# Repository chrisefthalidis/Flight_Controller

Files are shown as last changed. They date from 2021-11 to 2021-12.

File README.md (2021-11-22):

This board is an embedded system based on the STM32F405RGT6 microcontroller. It incorporates an MPU9250 Inertial
Measurement Unit for attitude estimation, an SPL06-007 barometer for altitude estimation and a TESEO-LIV3F GNSS
receiver for position estimation. There is also a second Radio Transceiver board (based on the nRF24L01+ transceiver)
that is connected as a shield to the Flight Controller board. You will find all the necessary PCB design files from
Altium and KiCad inside the respective folders. The firmware is not fully finished yet, but you will find most of the
existing files inside the 'Firmware' folder, including ST's HAL drivers generated by STM32CubeMX, an SPL06-007
driver, an nRF24L01+ driver, a Complementary Filter implementation in C, a Kalman Filter implementation in C++, as well
as a PID Controller implementation in both C and C++. The MPU9250 driver, as well as the main.c function are coming
soon. The basic idea is that we read the values from all our sensors, we deploy some state estimation and sensor
fusion algorithms, and we use these states to control a quadcopter UAV. There is also an additional 'Radio Controller
(Ground Module)' board, that you will find on my GitHub page, which we can use to remotely control the quadcopter's
altitude using the on-board potentiometer.

P.S. These boards are not perfect in any way. They have some design mistakes, since they were 2 of my first boards.
I've learnt a lot since, and i keep getting better with each board that i design. If you have any questions, please
contact me at chrisefthalidis@gmail.com

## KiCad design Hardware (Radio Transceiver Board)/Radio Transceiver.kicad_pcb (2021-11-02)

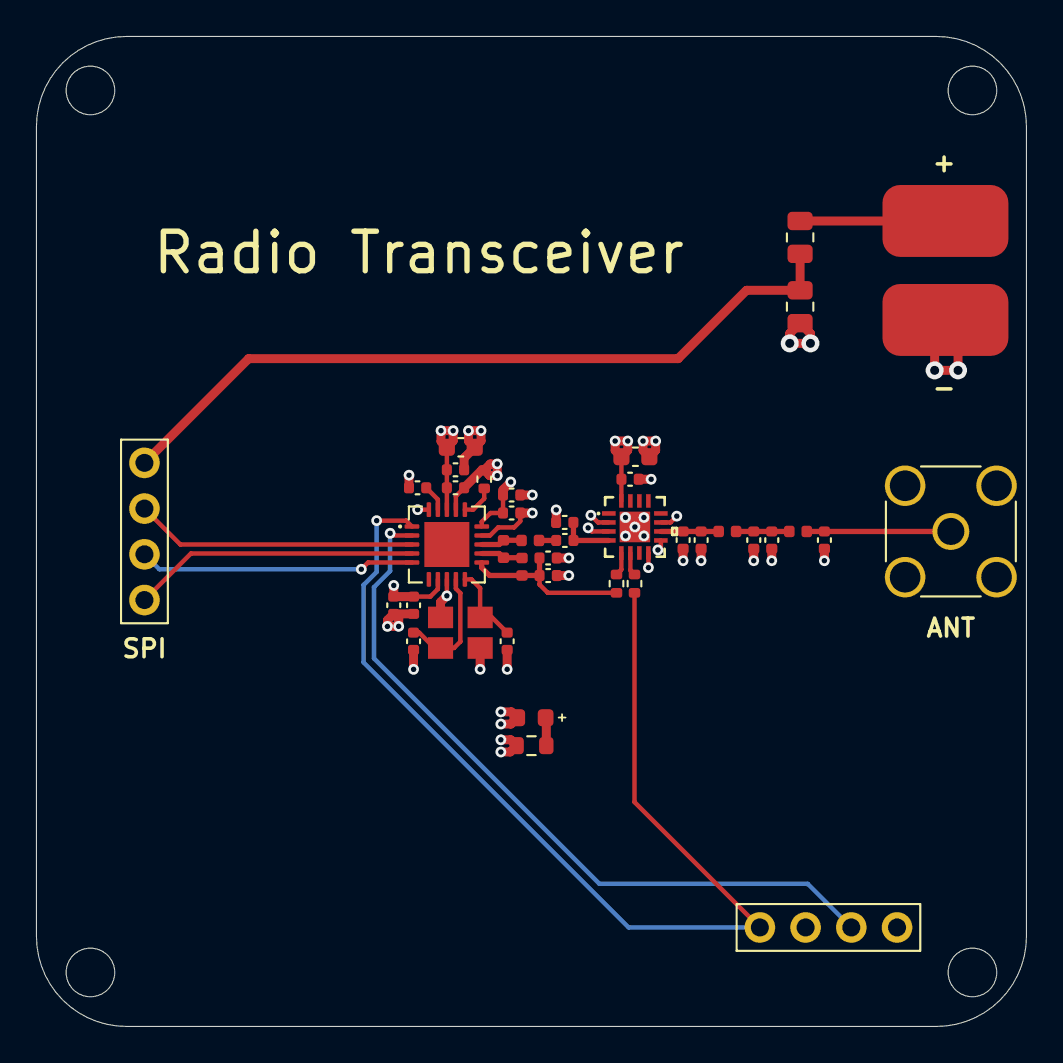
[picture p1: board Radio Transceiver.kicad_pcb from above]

Board: 4 copper layers, 55.0 x 55.0 mm, 44 parts (0 on the bottom side), 24 nets.

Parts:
C1: 1uF; C_0603_1608Metric
C2: 220pF; C_0402_1005Metric
C3: 4.7uF; C_0603_1608Metric
C4, C6, C8: 10nF; C_0402_1005Metric
C5, C7, C9: 1nF; C_0402_1005Metric
C10: 4.7pF; C_0402_1005Metric
C11: 2.2nF; C_0402_1005Metric
C12, C18, C19, C20, C21: 1.5pF; C_0402_1005Metric
C13: 1pF; C_0402_1005Metric
C14: 33nF; C_0402_1005Metric
C15, C16: 12pF; C_0402_1005Metric
C17: 0.3pF; C_0402_1005Metric
D1: Green LED; LED_0603_1608Metric
H1, H2, H3, H4: MountingHole; MountingHole_2.7mm_M2.5
J1: KH-SMA-KE8-G; SMA_Amphenol_132291_Vertical
J2, J3: Conn_01x04; PinSocket_1x04_P2.54mm_Vertical
J4: Screw_Terminal_01x02; TerminalBlock_bornier-2_P5.08mm
L1: 2.7nH; L_0402_1005Metric
L2: 8.2nH; L_0402_1005Metric
L3: 3.9nH; L_0402_1005Metric
L4, L5: 2.4nH; L_0402_1005Metric
R1, R2: 1KΩ; R_0402_1005Metric
R3: 22ΚΩ; R_0402_1005Metric
R4: 33Ω; R_0603_1608Metric
R5: 30ΚΩ; R_0805_2012Metric
R6: 7.5ΚΩ; R_0805_2012Metric
U1: RFX2401C
U2: nRF24L01P; QFN-20-1EP_4x4mm_P0.5mm_EP2.5x2.5mm
Y1: X322516MLB4SI; Crystal_SMD_3225-4Pin_3.2x2.5mm

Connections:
+3V3: C1.1, C2.1, C3.1, C4.1, C5.1, C6.1, C7.1, C8.1, C9.1, J2.1, R4.1, U1.16, U2.7, U2.15, U2.18
+BATT: J4.1, R5.2
/ADC_IN: J3.4, R5.1, R6.2
/ANT: C17.1, C18.1, L4.2, U1.10
/ANT1: L1.2, L2.1, U2.12
/ANT2: L2.2, L3.2, U2.13
/CE: J2.4, R2.1, U2.1
/CSN: J2.2, U2.2
/MISO: J3.2, U2.5
/MOSI: J3.1, U2.4
/SCK: J3.3, U2.3
/TXRX: C12.1, C13.1, U1.4
/VDD_PA: C10.1, C11.1, L1.1, R1.1, U2.11
/XC1: C15.1, U2.10, Y1.1
/XC2: C16.1, U2.9, Y1.3
GND: C1.2, C2.2, C3.2, C4.2, C5.2, C6.2, C7.2, C8.2, C9.2, C10.2, C11.2, C13.2, C14.2, C15.2, C16.2, C17.2, C18.2, C19.2, C20.2, C21.2, D1.1, J1.2, J2.3, J4.2, R3.1, R6.1, U1.2, U1.3, U1.8, U1.9, U1.11, U1.17, U2.8, U2.14, U2.17, U2.20, Y1.2, Y1.4
unnamed: C12.2, L3.1
unnamed: C14.1, U2.19
unnamed: C19.1, C20.1, L4.1, L5.2
unnamed: C21.1, J1.1, L5.1
unnamed: D1.2, R4.2
unnamed: R1.2, U1.5
unnamed: R2.2, U1.6
unnamed: R3.2, U2.16

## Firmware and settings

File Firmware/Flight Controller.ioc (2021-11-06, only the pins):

Mcu.UserName=STM32F405RGTx
PA10.Signal=GPIO_Output
PA11.Signal=USB_OTG_FS_DM
PA12.Signal=USB_OTG_FS_DP
PA13.Signal=GPIO_Output
PA14.Signal=GPIO_Output
PA15.Signal=S_TIM2_CH1_ETR
PA2.Signal=S_TIM2_CH3
PA4.Signal=ADCx_IN4
PA5.Signal=SPI1_SCK
PA6.Signal=SPI1_MISO
PA7.Signal=SPI1_MOSI
PA8.Signal=I2C3_SCL
PA9.Signal=GPIO_Output
PB10.Signal=I2C2_SCL
PB11.Signal=I2C2_SDA
PB14.Signal=S_TIM12_CH1
PB6.Signal=I2C1_SCL
PB7.Signal=I2C1_SDA
PB9.Signal=S_TIM4_CH4
PC11.Signal=GPIO_Output
PC12.Signal=GPIO_Input
PC2.Signal=GPIO_Output
PC3.Signal=GPIO_Input
PC4.Signal=GPIO_Output
PC5.Signal=GPIO_Input
PC7.Signal=GPIO_Output
PC8.Signal=GPIO_Input
PC9.Signal=I2C3_SDA
PH0-OSC_IN.Signal=RCC_OSC_IN
PH1-OSC_OUT.Signal=RCC_OSC_OUT

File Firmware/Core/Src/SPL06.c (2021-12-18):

#include "SPL06.h"

void SPL06_Read_Register(uint8_t dev_addr, uint8_t reg_addr, uint8_t *data)
{
  HAL_I2C_Mem_Read(&hi2c1, dev_addr, reg_addr, I2C_MEMADD_SIZE_8BIT, data, 1, HAL_MAX_DELAY);
}

void SPL06_Read_Registers(uint8_t dev_addr, uint8_t reg_addr, uint8_t *data, uint8_t length)
{
  HAL_I2C_Mem_Read(&hi2c1, dev_addr, reg_addr, I2C_MEMADD_SIZE_8BIT, data, length, HAL_MAX_DELAY);
}

void SPL06_Write_Register(uint8_t dev_addr, uint8_t reg_addr, uint8_t *data)
{
  HAL_I2C_Mem_Write(&hi2c1, dev_addr, reg_addr, I2C_MEMADD_SIZE_8BIT, data, 1, HAL_MAX_DELAY);
}

void SPL06_Write_Registers(uint8_t dev_addr, uint8_t reg_addr, uint8_t *data, uint8_t length)
{
  HAL_I2C_Mem_Write(&hi2c1, dev_addr, reg_addr, I2C_MEMADD_SIZE_8BIT, data, length, HAL_MAX_DELAY);
}

void SPL06_Initialise(SPL06 *dev)
{
  dev->c00 = 0;
  dev->c10 = 0;

  dev->c20 = 0;
  dev->c30 = 0;
  dev->c01 = 0;
  dev->c11 = 0;
  dev->c21 = 0;

  dev->bar_bias = 0.f;
  dev->bar_alt_m = 0.f;

  uint8_t tx_data, rx_data[15];

  tx_data = 0x61; // Pressure measurement rate: 64, Pressure oversampling rate: 2
  SPL06_Write_Register(SPL06_ADDR, SPL06_REG_PRS_CFG, &tx_data);

  tx_data = 0xA1; // Temperature measurement rate: 4, Temperature oversampling rate: 2
  SPL06_Write_Register(SPL06_ADDR, SPL06_REG_TMP_CFG, &tx_data);

  tx_data = 0b0111; // Continuous pressure and temperature measurement
  SPL06_Write_Register(SPL06_ADDR, SPL06_REG_MEAS_CFG, &tx_data);

  // Read the Calibration Coefficients register
  SPL06_Read_Registers(SPL06_ADDR, SPL06_REG_COEF, rx_data, sizeof(rx_data));

  // Calculate the Calibration Coefficients
  dev->c00 = ((uint32_t)rx_data[0] << 12) | ((uint16_t)rx_data[1] << 4) | ((uint16_t)rx_data[2] >> 4);
  dev->c10 = ((uint32_t)(rx_data[2] & 0x0F)) << 16 | ((uint16_t)rx_data[3] << 8) | rx_data[4];
  dev->c01 = ((uint16_t)rx_data[5] << 8) | rx_data[6];
  dev->c11 = ((uint16_t)rx_data[7] << 8) | rx_data[8];
  dev->c20 = ((uint16_t)rx_data[9] << 8) | rx_data[10];
  dev->c21 = ((uint16_t)rx_data[11] << 8) | rx_data[12];
  dev->c30 = ((uint16_t)rx_data[13] << 8) | rx_data[14];

  if (dev->c00 & (1 << 19))
    dev->c00 = dev->c00 | 0xFFF00000;

  if (dev->c10 & (1 << 19))
    dev->c10 = dev->c10 | 0xFFF00000;
}

void SPL06_Calibrate(SPL06 *dev)
{
  float avg_bar_bias = 0.f;

  // Take 2000 measurements and average them to get the bias
  for (uint16_t i = 0; i < 2010; i++)
  {
    SPL06_Read(dev);

    if (i >= 10)
      avg_bar_bias += dev->bar_alt_m;

    HAL_Delay(10);
  }

  dev->bar_bias = avg_bar_bias / 2000;
}

void SPL06_Read(SPL06 *dev)
{
  uint8_t data[6];
  int32_t press_raw = 0, temp_raw = 0;
  float press_raw_scaled = 0.f, temp_raw_scaled = 0.f, press_hPa = 0.f;

  // Read all the data registers
  SPL06_Read_Registers(SPL06_ADDR, SPL06_REG_PSR_B2, data, sizeof(data));

  // Calculate raw pressure and temperature values
  press_raw = ((uint32_t)data[0] << 16) | ((uint16_t)data[1] << 8) | data[2];
  temp_raw = ((uint32_t)data[3] << 16) | ((uint16_t)data[4] << 8) | data[5];

  if (press_raw & (1 << 23))
    press_raw = press_raw | 0xFF000000;

  if (temp_raw & (1 << 23))
    temp_raw = temp_raw | 0xFF000000;

  press_raw_scaled = (float)press_raw / 1572864.f;
  temp_raw_scaled = (float)temp_raw / 1572864.f;

  // Convert the raw values into pressure in hPa
  press_hPa = ((float)dev->c00 + press_raw_scaled * ((float)dev->c10 + press_raw_scaled * ((float)dev->c20 + press_raw_scaled * (float)dev->c30)) +
               temp_raw_scaled * (float)dev->c01 + temp_raw_scaled * press_raw_scaled * ((float)dev->c11 + press_raw_scaled * (float)dev->c21)) /
              100.f;

  // Convert the pressure in hPa into altitude in meters
  dev->bar_alt_m = 44330.f * (1.f - powf(press_hPa / 1013.25f, 1.f / 5.255f));

  // Subtract the bias
  dev->bar_alt_m -= dev->bar_bias;
}

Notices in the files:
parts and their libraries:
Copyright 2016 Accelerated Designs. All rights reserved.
